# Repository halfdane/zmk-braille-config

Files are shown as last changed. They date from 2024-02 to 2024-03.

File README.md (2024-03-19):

# Braille Keyboard
A 10 keys ortholinear mini-keyboard that connects via bluetooth.
Pressing the central six keys in braille patterns will send the corresponding keypresses to the host.

Find an example case in the directory [`case`](case)

## Features
- All german letters, numbers and symbols of grade 1
- Connects to up to five bluetooth hosts which can be changed on the fly
- [Haptic feedback](#haptic-feedback)
- Supports the complete german "Vollschrift" (i.e. grade 1): [patterns](de.md)
- Reset into bootloader mode for firmware updates
- Case can be 3D-printed
- rev2 (default) uses direct pin - so diodes aren't necessary for the matrix

## Missing Features
- No math mode
- No other languages
- Settings and Navigation etc. are confusing and undocumented

## Haptic Feedback
Uses the https://github.com/halfdane/zmk-behavior-haptic-feedback module to make a vibration motor go brr.

## Local development
Automatic setup expects you to run linux. 
On MacOS, it might just work with some changes, but you're on your own there.

`make west_setup` # this takes a while

Run `make` or `make all` to compile the firmware and copy it to your NICENANO.
`make clean` just removes the build dir, while `make deep_clean` removes all dependencies so you have to run `make west_setup` again.

`make follow` invokes the `tio` command to watch log messages fly by. It's lovely 🤗

## Roadmap
- build an MVC with
    - [x] xiao ble (instead of half broken nice!nano)
    - [x] 3d print a case (instead of using massive amounts of hot glue)
    - [x] a proper rumble motor (instead of soldering metal to the axis of a small motor)
    - [x] direct pin instead of a matrix (no diodes)
    - [x] batteries (instead of using a power bank because the loading circuit was fried years ago)
- try to combine the braille tables of liblouis with CLDR keyboard descriptions to automatically generate languages
- [x] activating the rumble motor is currently blocking the main thread - make it concurrent
- create a '1.0' version ("slimline")
    - smd components on a tiny pcb
    - repairable case (esp. openable)

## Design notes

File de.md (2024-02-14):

Name, Output, Cell, Dots
a, a, ⠁, 1
b, b, ⠃, 1 2
c, c, ⠉, 1 4
d, d, ⠙, 1 4 5
e, e, ⠑, 1 5
f, f, ⠋, 1 2 4
g, g, ⠛, 1 2 4 5
h, h, ⠓, 1 2 5
i, i, ⠊, 2 4
j, j, ⠚, 2 4 5
k, k, ⠅, 1 3
l, l, ⠇, 1 2 3
m, m, ⠍, 1 3 4
n, n, ⠝, 1 3 4 5
o, o, ⠕, 1 3 5
p, p, ⠏, 1 2 3 4
q, q, ⠟, 1 2 3 4 5
r, r, ⠗, 1 2 3 5
s, s, ⠎, 2 3 4
t, t, ⠞, 2 3 4 5
u, u, ⠥, 1 3 6
v, v, ⠧, 1 2 3 6
w, w, ⠺, 2 4 5 6
x, x, ⠭, 1 3 4 6
y, y, ⠽, 1 3 4 5 6
z, z, ⠵, 1 3 5 6
ä, ä, ⠜, 3 4 5
ö, ö, ⠪, 2 4 6
ü, ü, ⠳, 1 2 5 6
ß, ß, ⠮, 2 3 4 6
au, au, ⠡, 1 6
äu, äu, ⠌, 3 4
ei, ei, ⠩, 1 4 6
ie, ie, ⠬, 3 4 6
eu, eu, ⠣, 1 2 6
ch, ch, ⠹, 1 4 5 6
sch, sch, ⠱, 1 5 6
st, st, ⠾, 2 3 4 5 6

Zahlzeichen, ⠼, 3 4 5 6
1, 1, ⠁, 1
2, 2, ⠃, 1 2
3, 3, ⠉, 1 4
4, 4, ⠙, 1 4 5
5, 5, ⠑, 1 5
6, 6, ⠋, 1 2 4
7, 7, ⠛, 1 2 4 5
8, 8, ⠓, 1 2 5
9, 9, ⠊, 2 4
0, 0, ⠚, 2 4 5

Komma, \,, ⠂, 2
Semikolon, ;, ⠆, 2 3
Doppelpunkt, :, ⠒, 2 5
Fragezeichen, ?, ⠢, 2 6
Ausrufezeichen, !, ⠖, 2 3 5
Klammer auf, (, ⠶, 2 3 5 6
Anführungszeichen, ", ⠦, 2 3 6
Anführungszeichen, ", ⠴, 3 5 6
Paragraph, §, ⠬, 3 4 6, ENTFÄLLT WG. KONFLIKT MIT 'IE'
Punkt, ., ⠄, 3
Minus, -, ⠤, 3 6
Apostroph, ', ⠠, 6

Ankündigung eines Großbuchstabens, one shot shift, ⠨, 4 6
Ankündigung mehrerer Großbuchstaben, CapsWord, ⠘, 4 5

Gedankenstrich, -, ⠠⠤, 6 - 3 6
Abtrennungszeichen, (senkrechter Strich), |, ⠐⠤, 5 - 3 6
Eckige Klammer auf, [, ⠠⠶, 6 - 2 3 5 6
Spitze Klammer auf, <, ⠐⠶, 5 - 2 3 5 6
Geschweifte Klammer auf, {, ⠐⠷, 5 - 1 2 3 5 6
Phonetische Klammer auf, [, ⠘⠷, 4 5 - 1 2 3 5 6
Phonetische Klammer zu, ], ⠘⠾, 4 5 - 2 3 4 5 6
Phonemische Klammer auf und zu, /, ⠘⡈, 4 5 - 3 4
"einfaches" Anführungszeichen am Anfang, ', ⠠⠦, 6 - 2 3 6
"einfaches" Anführungszeichen am Ende, `, ⠠⠴, 6 - 3 5 6
Schrägstrich, /, ⠐⠂, 5 - 2
Et-Zeichen, ("Kaufmännisches Und"), &, ⠐⠥, 5 - 1 3 6
Stern, *, ⠠⠔, 6 - 3 5
Prozentzeichen, %, ⠼⠚⠴, 3 4 5 6 - 2 4 5 - 3 5 6
Gradzeichen, °, ⠈⠴, 4 - 3 5 6
Backslash, \, ⠈⡈, 4 - 3 4
AT, @, ⠈⠜, 4 - 3 4 5
Unterstrich, _, ⠈⠸, 4 - 4 5 6
Hash, #, ⠈⠼, 4 - 3 4 5 6
Euro, €, ⠈⠑, 4 - 1 5
Dollar, $, ⠈⠎, 4 - 2 3 4
(Dollar-)Centzeichen, ¢, ⠈⠉, 4 - 1 4
Pfund- oder Lirazeichen (Währungsangaben), £, ⠈⠇, 4 - 1 2 3

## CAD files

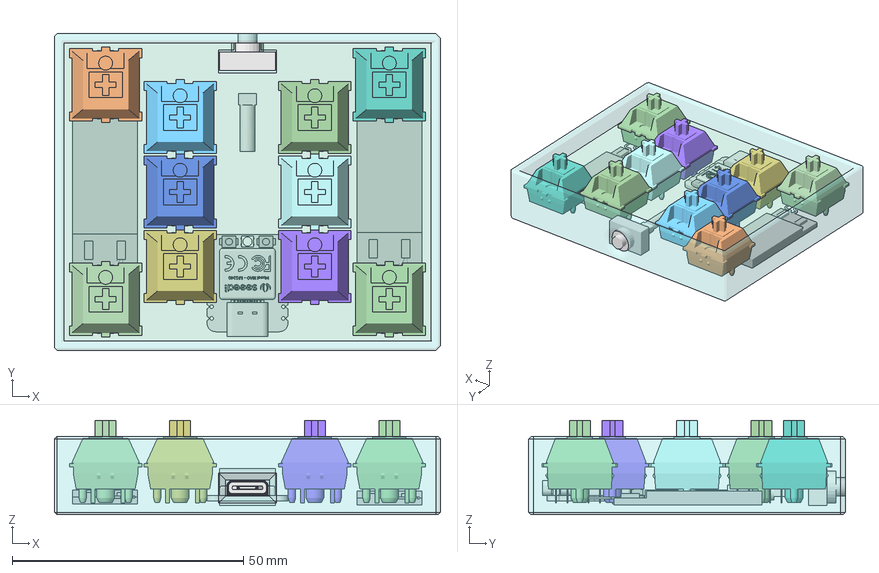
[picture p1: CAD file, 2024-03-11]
case/braille_keyboard.FCStd
83.4 x 68.4 x 20.4 mm
type-c v2
smd_button v3
DOUT
DIN
VSS
VDD
smd_button v3(Mirror)
power_switch
rumbler
Battery
Battery001
case
switchplate
switch_mx009
switch_mx008
switch_mx007
switch_mx006
switch_mx005
switch_mx004
switch_mx003
switch_mx002
switch_mx001
switch_mx

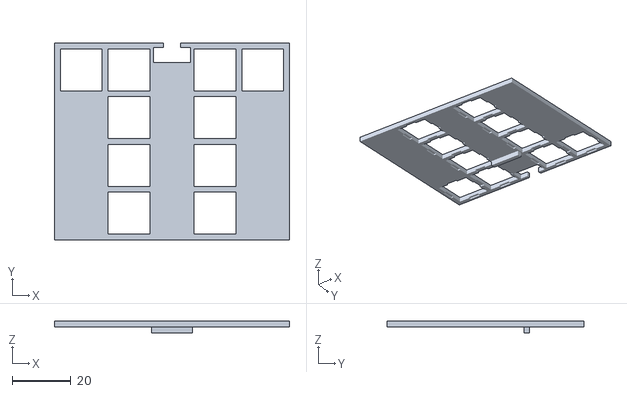
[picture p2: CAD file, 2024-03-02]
case/braille_keyboard-switchplate.stl
79.8 x 66.8 x 4.00

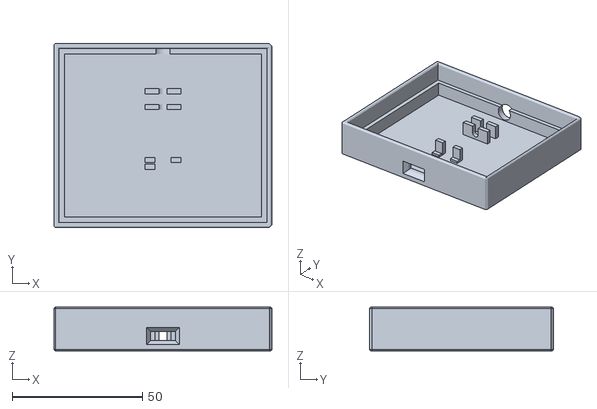
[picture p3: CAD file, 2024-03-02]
case/braille_keyboard-case.stl
83.8 x 70.8 x 16.9

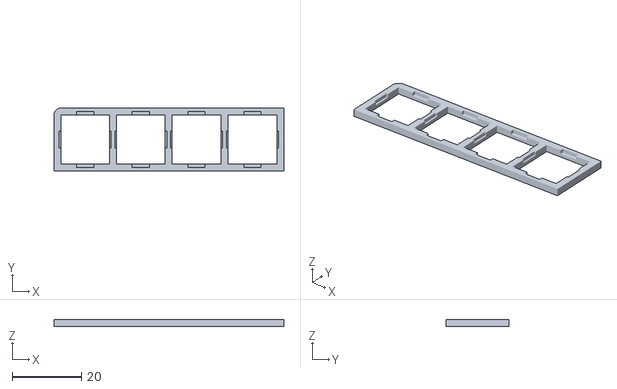
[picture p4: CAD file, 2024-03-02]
case/braille_keyboard-switchtest.stl
66.5 x 18.2 x 2.00

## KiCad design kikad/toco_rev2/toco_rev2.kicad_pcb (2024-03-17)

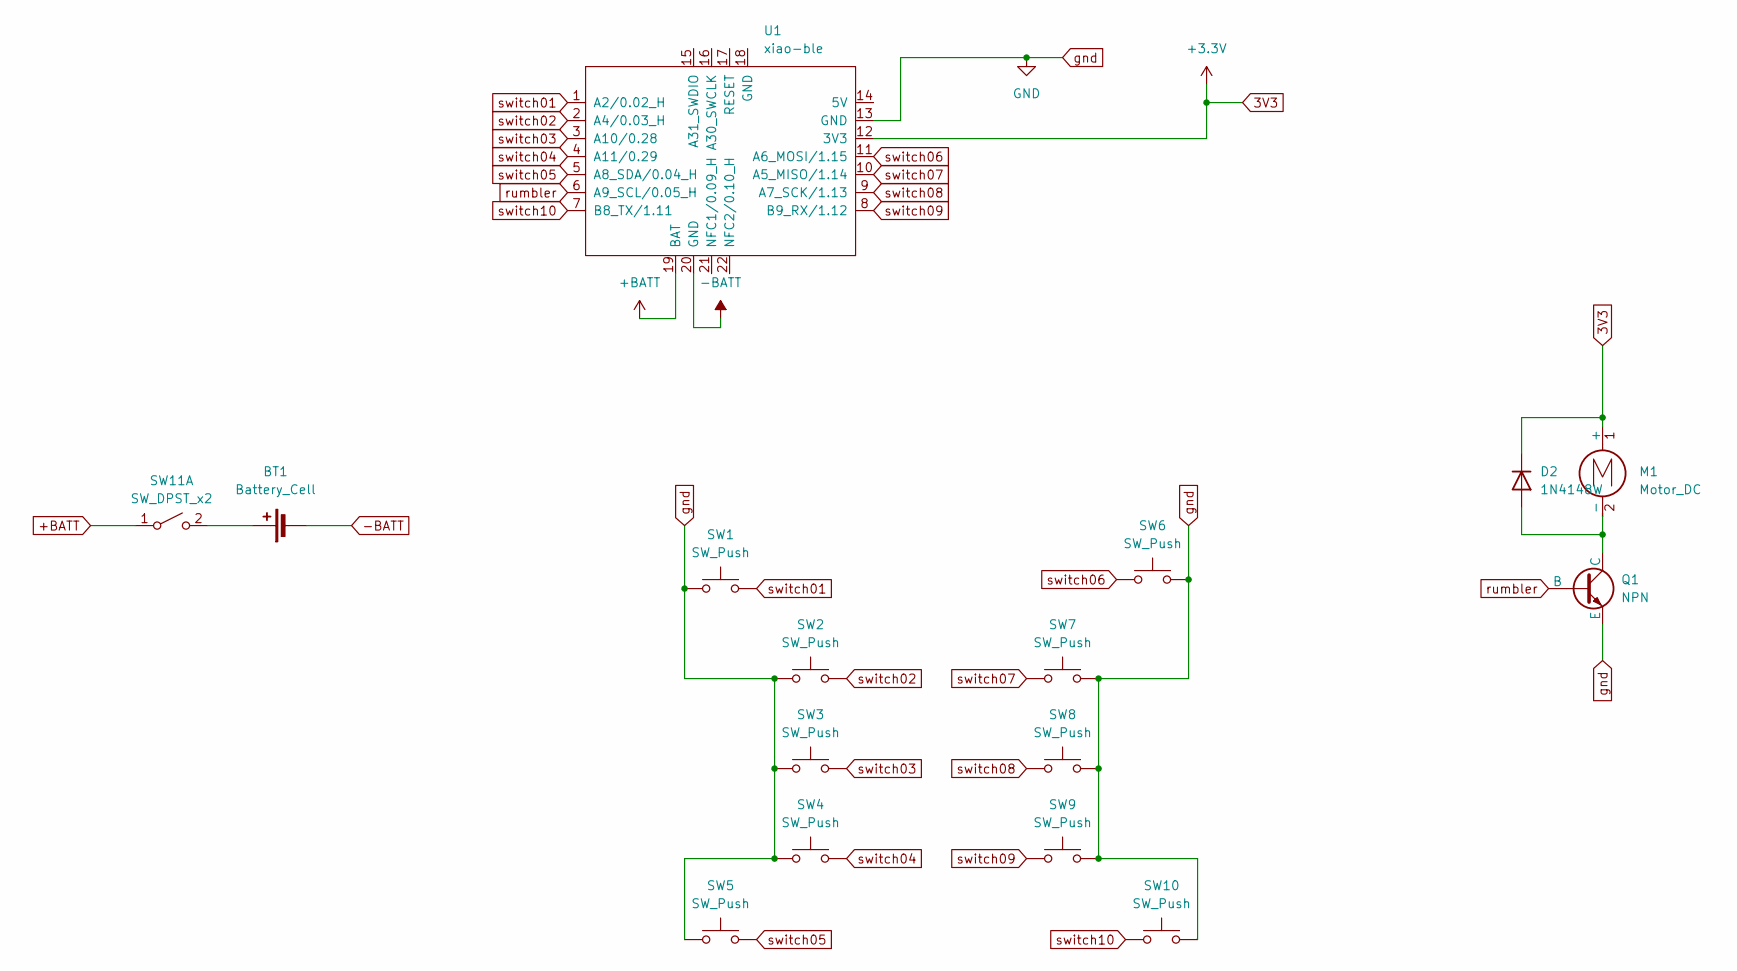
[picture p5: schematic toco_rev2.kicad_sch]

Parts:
BT1: Battery_Cell; SolderWire-0.5sqmm_1x02_P4.6mm_D0.9mm_OD2.1mm
D2: 1N4148W; D_SOD-123
M1: Motor_DC; SolderWire-0.5sqmm_1x02_P4.6mm_D0.9mm_OD2.1mm
Q1: NPN; SOT-23
SW1, SW2, SW3, SW4, SW5, SW6, SW7, SW8, SW9, SW10: SW_Push; SW_SPST_EVQP0
SW11: SW_DPST_x2; SW_SPDT_PCM12
U1: xiao-ble; xiao-ble-tht

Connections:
3V3: D2.1 (K), M1.1 (+), U1.12 (3V3)
+BATT: SW11.1 (A), U1.19 (BAT)
-BATT: BT1.2 (-), U1.20 (GND)
unnamed: BT1.1 (+), SW11.2 (B)
unnamed: D2.2 (A), M1.2 (-), Q1.1 (C)
gnd: Q1.3 (E), SW1.1, SW2.1, SW3.1, SW4.1, SW5.1, SW6.2, SW7.2, SW8.2, SW9.2, SW10.2, U1.13 (GND)
rumbler: Q1.2 (B), U1.6 (A9_SCL/0.05_H)
switch01: SW1.2, U1.1 (A2/0.02_H)
switch02: SW2.2, U1.2 (A4/0.03_H)
switch03: SW3.2, U1.3 (A10/0.28)
switch04: SW4.2, U1.4 (A11/0.29)
switch05: SW5.2, U1.5 (A8_SDA/0.04_H)
switch06: SW6.1, U1.11 (A6_MOSI/1.15)
switch07: SW7.1, U1.10 (A5_MISO/1.14)
switch08: SW8.1, U1.9 (A7_SCK/1.13)
switch09: SW9.1, U1.8 (B9_RX/1.12)
switch10: SW10.1, U1.7 (B8_TX/1.11)

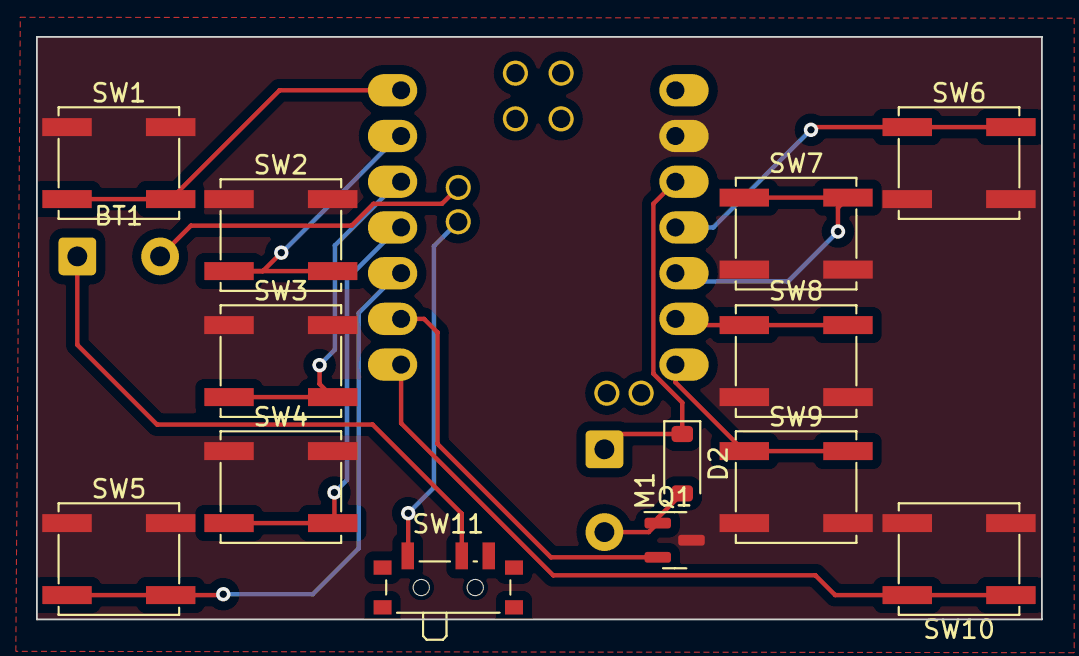
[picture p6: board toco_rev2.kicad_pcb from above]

Board: 2 copper layers, 55.8 x 32.4 mm, 16 parts (0 on the bottom side), 17 nets.

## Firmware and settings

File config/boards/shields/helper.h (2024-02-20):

/*
 * helper.h
 *
 * Convenience macros simplifying ZMK's keymap configuration.
 * See https://github.com/urob/zmk-nodefree-config for documentation.
 */

#pragma once

#define ZMK_HELPER_STRINGIFY(x) #x

/* ZMK_BEHAVIOR */

#define ZMK_BEHAVIOR_CORE_caps_word       compatible = "zmk,behavior-caps-word";       #binding-cells = <0>
#define ZMK_BEHAVIOR_CORE_dynamic_macro   compatible = "zmk,behavior-dynamic-macro";   #binding-cells = <1>
#define ZMK_BEHAVIOR_CORE_hold_tap        compatible = "zmk,behavior-hold-tap";        #binding-cells = <2>
#define ZMK_BEHAVIOR_CORE_key_repeat      compatible = "zmk,behavior-key-repeat";      #binding-cells = <0>
#define ZMK_BEHAVIOR_CORE_macro           compatible = "zmk,behavior-macro";           #binding-cells = <0>
#define ZMK_BEHAVIOR_CORE_macro_one_param compatible = "zmk,behavior-macro-one-param"; #binding-cells = <1>
#define ZMK_BEHAVIOR_CORE_macro_two_param compatible = "zmk,behavior-macro-two-param"; #binding-cells = <2>
#define ZMK_BEHAVIOR_CORE_mod_morph       compatible = "zmk,behavior-mod-morph";       #binding-cells = <0>
#define ZMK_BEHAVIOR_CORE_sticky_key      compatible = "zmk,behavior-sticky-key";      #binding-cells = <1>
#define ZMK_BEHAVIOR_CORE_tap_dance       compatible = "zmk,behavior-tap-dance";       #binding-cells = <0>
#define ZMK_BEHAVIOR_CORE_tri_state       compatible = "zmk,behavior-tri-state";       #binding-cells = <0>

#define ZMK_BEHAVIOR(name, type, ...) \
    / { \
        behaviors { \
            name: name { \
                ZMK_BEHAVIOR_CORE_ ## type; \
                __VA_ARGS__ \
            }; \
        }; \
    };

/* ZMK_LAYER */

#define MACRO_CHOOSER3(_1, _2, _3, FUNC, ...) FUNC
#define ZMK_LAYER(...) MACRO_CHOOSER3(__VA_ARGS__, ZMK_LAYER_3_ARGS, ZMK_LAYER_2_ARGS)(__VA_ARGS__)
#define ZMK_LAYER_2_ARGS(name, layout) \
    / { \
        keymap { \
            compatible = "zmk,keymap"; \
            layer_ ## name { \
                bindings = <layout>; \
            }; \
        }; \
    };
#define ZMK_LAYER_3_ARGS(name, layout, sensors) \
    / { \
        keymap { \
            compatible = "zmk,keymap"; \
            layer_ ## name { \
                bindings = <layout>; \
                sensor-bindings = <sensors>; \
            }; \
        }; \
    };

/* ZMK_COMBOS */

#define ALL 0xff
#if !defined COMBO_TERM
    #define COMBO_TERM 30
#endif
#if !defined COMBO_HOOK
    #define COMBO_HOOK
#endif

#define MACRO_CHOOSER5(_1, _2, _3, _4, _5, FUNC, ...) FUNC
#define ZMK_COMBO(...) MACRO_CHOOSER5(__VA_ARGS__, ZMK_COMBO_5_ARGS, ZMK_COMBO_4_ARGS)(__VA_ARGS__)
#define ZMK_COMBO_4_ARGS(name, combo_bindings, keypos, combo_layers) \
    ZMK_COMBO_5_ARGS(name, combo_bindings, keypos, combo_layers, COMBO_TERM)
#define ZMK_COMBO_5_ARGS(name, combo_bindings, keypos, combo_layers, combo_timeout) \
    / { \
        combos { \
            compatible = "zmk,combos"; \
            combo_ ## name { \
                timeout-ms = <combo_timeout>; \
                bindings = <combo_bindings>; \
                key-positions = <keypos>; \
                layers = <combo_layers>; \
                COMBO_HOOK \
            }; \
        }; \
    };

/* ZMK_CONDITIONAL_LAYER */

#define ZMK_CONDITIONAL_LAYER(if_layers, then_layer) \
    / { \
        conditional_layers { \
            compatible = "zmk,conditional-layers"; \
            tri_layer { \
                if-layers = <if_layers>; \
                then-layer = <then_layer>; \
            }; \
        }; \
    };

/* ZMK_UNICODE */

#if !defined OS_UNICODE_LEAD
    #if HOST_OS == 2
        #define OS_UNICODE_LEAD &macro_press &kp LALT      // macOS/Windows-Alt-Codes
    #elif HOST_OS == 1
        #define OS_UNICODE_LEAD &macro_tap &kp LS(LC(U))   // Linux
    #else
        #define OS_UNICODE_LEAD &macro_tap &kp RALT &kp U  // Windows + WinCompose (default)
    #endif
#endif
#if !defined OS_UNICODE_TRAIL
    #if HOST_OS == 2
        #define OS_UNICODE_TRAIL &macro_release &kp LALT  // macOS/Windows-Alt-Codes
    #elif HOST_OS == 1
        #define OS_UNICODE_TRAIL &macro_tap &kp SPACE     // Linux
    #else
        #define OS_UNICODE_TRAIL &macro_tap &kp RET       // Windows + WinCompose (default)
    #endif
#endif

#define UC_MACRO(name, unicode_bindings) \
    / { \
        macros { \
            name: name { \
                compatible = "zmk,behavior-macro"; \
                label = ZMK_HELPER_STRINGIFY(UC_MACRO_ ## name); \
                wait-ms = <0>; \
                tap-ms = <0>; \
                #binding-cells = <0>; \
                bindings = <OS_UNICODE_LEAD>, <&macro_tap unicode_bindings>, <OS_UNICODE_TRAIL>; \
            }; \
        }; \
    };

#define UC_MODMORPH(name, uc_binding, shifted_uc_binding) \
    / { \
        behaviors { \
            name: name { \
                compatible = "zmk,behavior-mod-morph"; \
                label = ZMK_HELPER_STRINGIFY(UC_MORPH_ ## name); \
                #binding-cells = <0>; \
                bindings = <uc_binding>, <shifted_uc_binding>; \
                mods = <(MOD_LSFT|MOD_RSFT)>; \
            }; \
        }; \
    };

#define ZMK_UNICODE_SINGLE(name, L0, L1, L2, L3) \
    UC_MACRO(name ## _lower, &kp L0 &kp L1 &kp L2 &kp L3) \
    UC_MODMORPH(name, &name ## _lower, &none)

#define ZMK_UNICODE_PAIR(name, L0, L1, L2, L3, U0, U1, U2, U3) \
    UC_MACRO(name ## _lower, &kp L0 &kp L1 &kp L2 &kp L3) \
    UC_MACRO(name ## _upper, &kp U0 &kp U1 &kp U2 &kp U3) \
    UC_MODMORPH(name, &name ## _lower, &name ## _upper)

#define BR_MACRO_COMBO(name, keys, dots, active_on_layer) \
    ZMK_BEHAVIOR(name, macro,  bindings = <&macro_tap keys>;)\
    ZMK_COMBO(name_combo, &name, dots, active_on_layer)

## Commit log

2024-02-11 first tap dance and bootloader without pin shorting
2024-02-11 switch to correct layer when double tapping top right
2024-02-15 it's a rumbler, not a buzzer
    [helper.h]
2024-02-20 use gpio instead of pwm for rumbler
2024-02-23 add case
    [braille_keyboard.FCStd]
2024-02-23 add chamfer around usb. no idea what the other file is
    [braille_keyboard.FCStd]
2024-02-23 fix unclosed switch plate
    [braille_keyboard.FCStd]
2024-02-24 probably print ready
    [braille_keyboard.FCStd, slim_case.stp, slim_switch_plate.stp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]
2024-02-24 fix weird glitch in slim case export
    [braille_keyboard.FCStd, slim_case.stp]
2024-02-24 add a model where mx switches don't interact with the case walls
    [braille_keyboard.FCStd, slimest_case.stp]
2024-02-26 right side up
    [braille_keyboard.FCStd]
2024-03-01 add more space for components
    [braille_keyboard.FCStd]
2024-03-01 remove obsolete STEP files
    [slim_case.stp, slim_switch_plate.stp, slimest_case.stp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]
2024-03-01 export meshes for printing
    [braille_keyboard-case.stl, braille_keyboard-switchplate.stl, braille_keyboard.FCStd]
2024-03-02 add a tester for switch holder
    [braille_keyboard-switchtest.stl, braille_keyboard.FCStd]
2024-03-02 add chamfer to *all* outer edges
    [braille_keyboard-case.stl]
2024-03-02 Adjust spacing around power switch
    [braille_keyboard-switchplate.stl]
2024-03-08 preserve current revision as 'initial' because it solves problems that'll probably arise again and again
2024-03-08 adjust keys layout
    [braille_keyboard.FCStd]
2024-03-11 make right half of switchplate identical to left part
    [braille_keyboard.FCStd]
2024-03-12 add correct pin layout
2024-03-14 documenting the schematic of revision 2
    [toco_rev2.kicad_pcb, toco_rev2.kicad_sch]
2024-03-17 fiddling whith pcb
    [toco_rev2.kicad_pcb, toco_rev2.kicad_sch]
2024-03-17 automatic kicad backups
